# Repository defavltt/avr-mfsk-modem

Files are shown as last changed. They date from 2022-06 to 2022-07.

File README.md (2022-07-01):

# AVR MFSK (Multiple Frequency Shift Keying) modem transceiver

Original project based on ATmega88/168

Goertzel FFT based tone decoding for noisy audio links

Made specifically for radio use

## Features

 - Serial configurable: base frequency, frequency spacing and rate (~14 bits per second)

 - Repeated transmission of last data sent for performance testing

 - Audio input clipping indication

 - Automatic PTT control output

 - Automatic valid data checking

 - 8-bit sinewave output for regular audio channels

 - Suitable for keyboard-to-keyboard terminal operation

## Operation

There are two modem modes: normal operation / configuration. They are toggled by pressing the button

Configuring the parameters and enabling repeated transmission is done by going into configuration mode and sending a number corresponding to a byte that each of the it's double bits is a parameter value.

| param name | bit position | 0 | 1 | 2 | 3 |
|---|---|-----|-----|---|---|
| rtrans | 0 | off | on  | - | - |
| base freq  | 2 | 375 | 750 | 1125 | 1500 |
| freq space | 4 | 50  | 100 | 150  | 200  |
| rate* | 6 | 15  | 25  | 35 | 45 |

*the smaller the value the higher the bit rate

Examples:
```
88 > (01 01 10 00) - rtrans off, bf 2, fs 1, r 1
89 > (01 01 10 01) - rtrans on,  bf 2, fs 1, r 1

152 > (10 01 10 00) - rtrans off, bf 2, fs 1, r 2
```

While in configuration mode the LED shows audio input clipping. To set proper input level, a tone from a modem should be played into the input and the level adjusted to where the LED stops flickering. A solid light means too much signal is being fed.

Transmitting data/message is done by sending it by serial in normal operation mode.
Receiving data/message is only done in normal operation mode and retrieved from serial.

LED stays constantly on while: catching a preamble, receiving data/message and transmitting data/message.

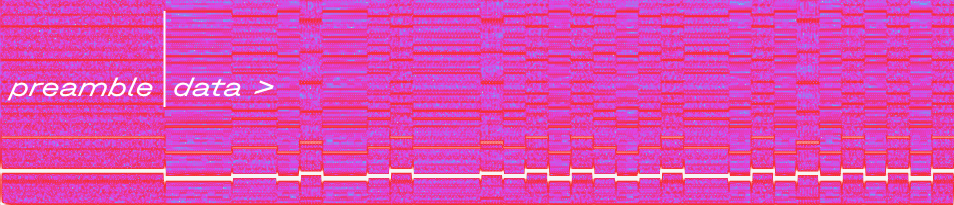
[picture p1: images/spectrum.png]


_spectral view of the transmission_

## Hardware

The PCB design is made for a 28-pin ATmega (QFN/MLF), whether that's 88, 168, 328, is a personal choice. Single-sided with some jumper wires required, vias are only for ground connection to the bottom layer.

Using an ATmega328 is encouraged, since originally an ATmega88 is used, flash usage is at ~99%, that limits adding more features.

There are pads left on the PCB for ISP programming and future use.

This project uses [MiniCore](https://github.com/MCUdude/MiniCore). Also a 16Mhz crystal is used.

Files for a 3D printed case are included. Case is held together by running a soldering iron along the seam of the top panel and main body.

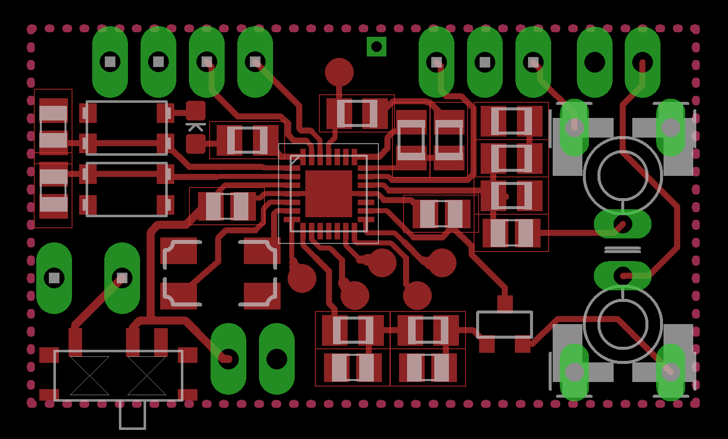
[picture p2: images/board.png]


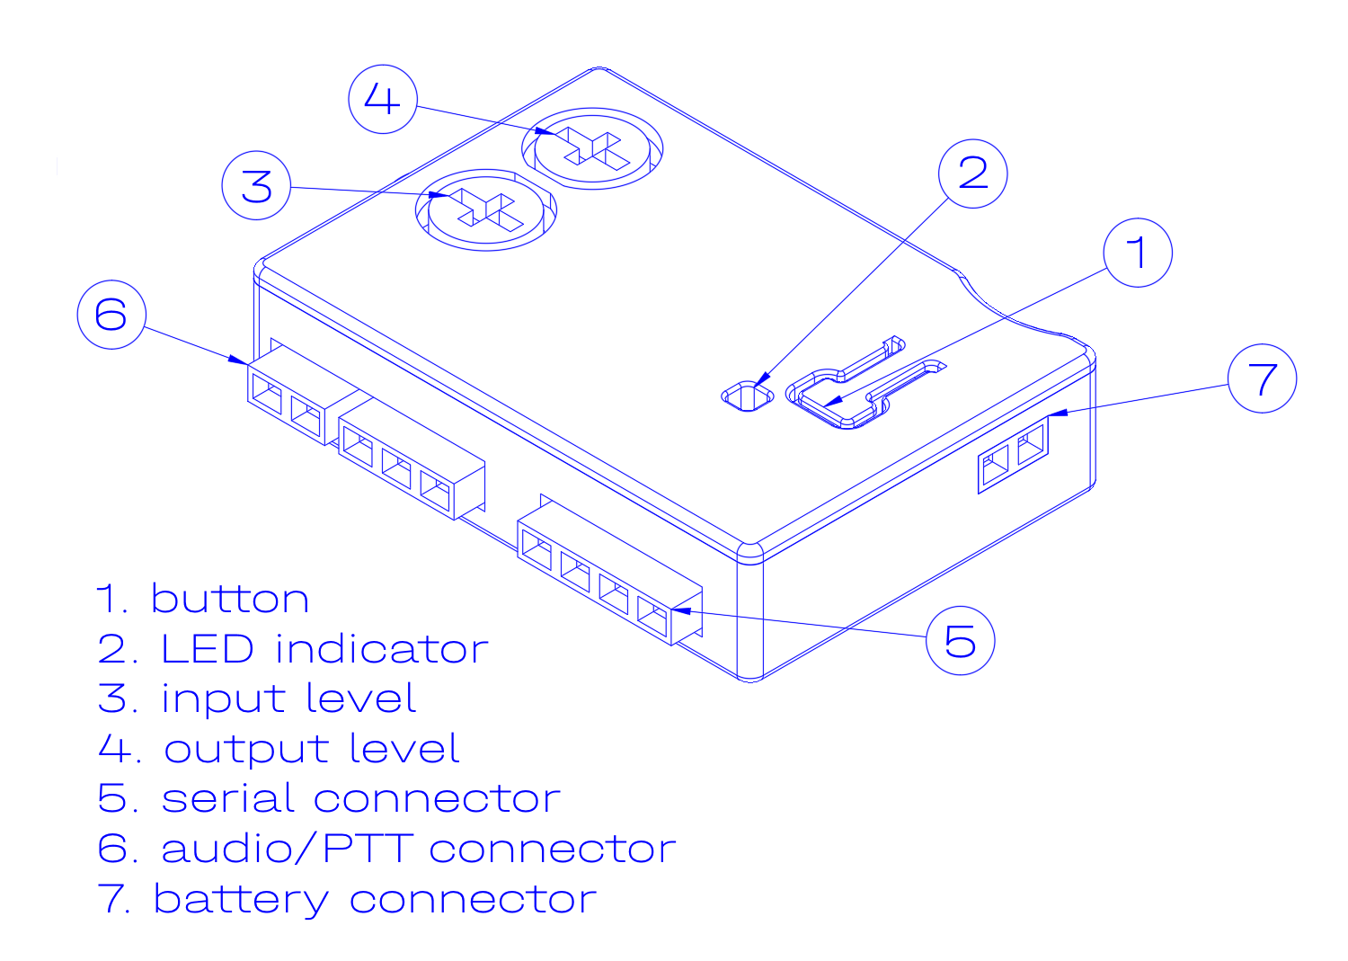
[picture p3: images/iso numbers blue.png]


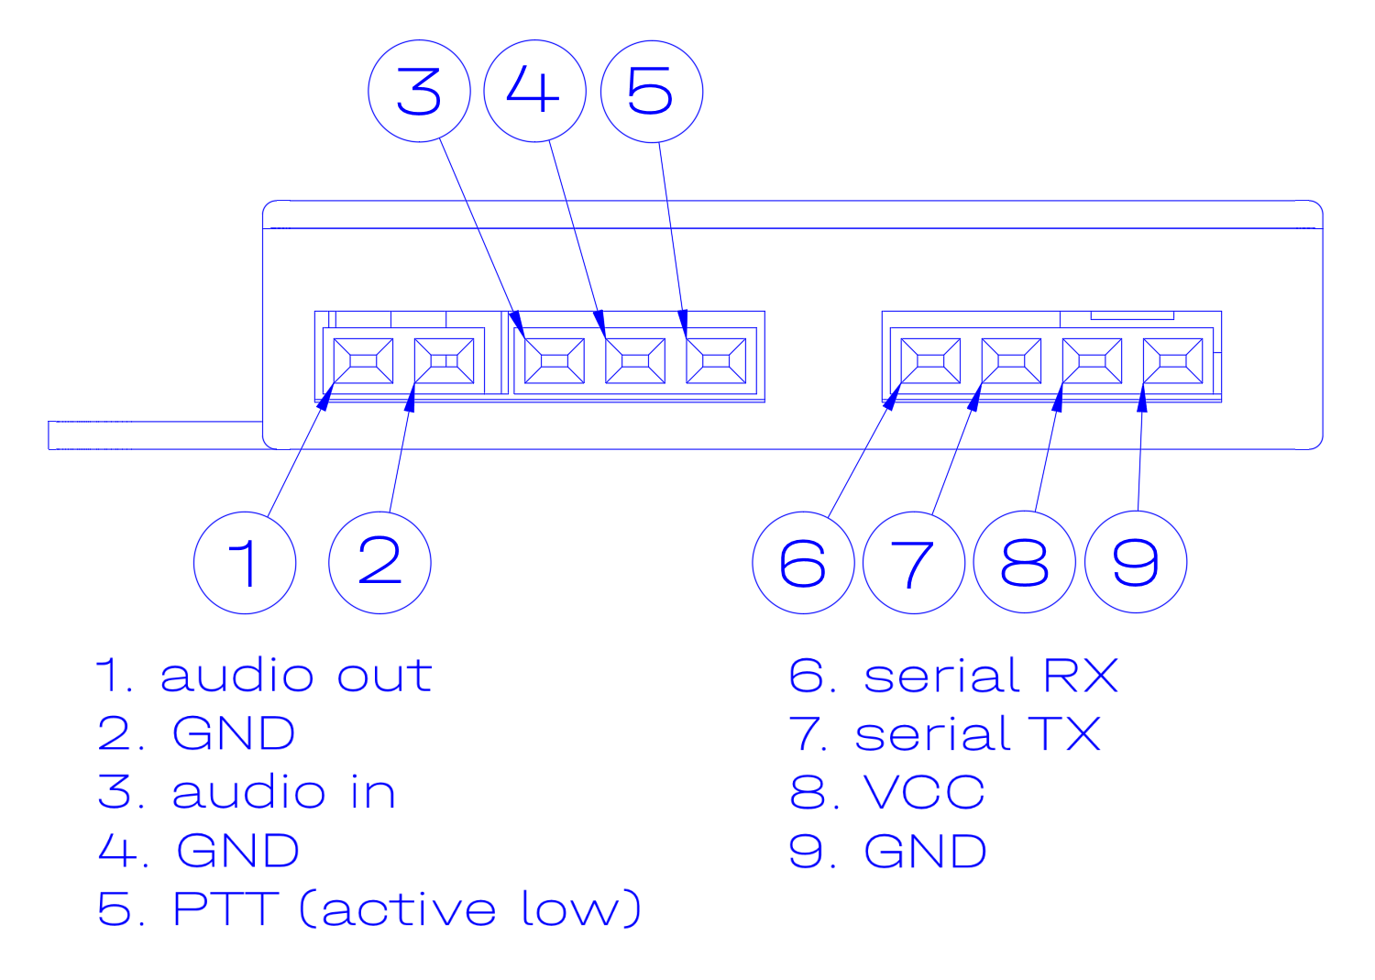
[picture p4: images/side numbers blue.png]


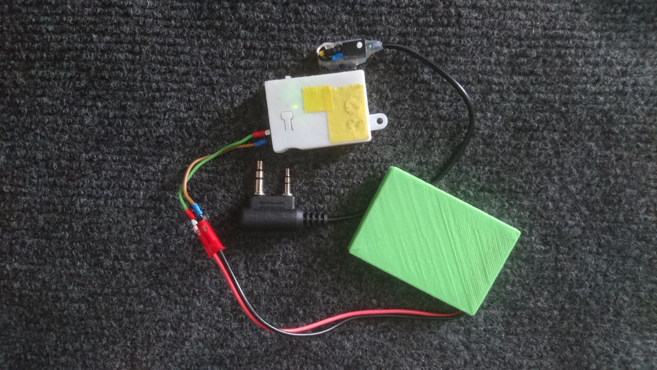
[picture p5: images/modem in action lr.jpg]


_modem powered on with a battery and connected with a kenwood style cable_

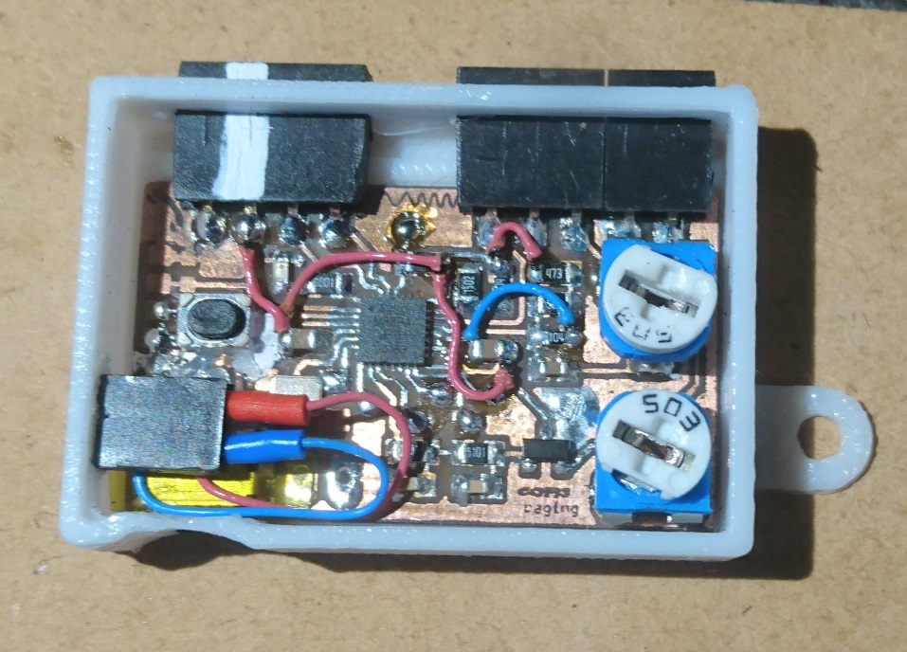
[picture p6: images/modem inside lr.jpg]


_bare modem_

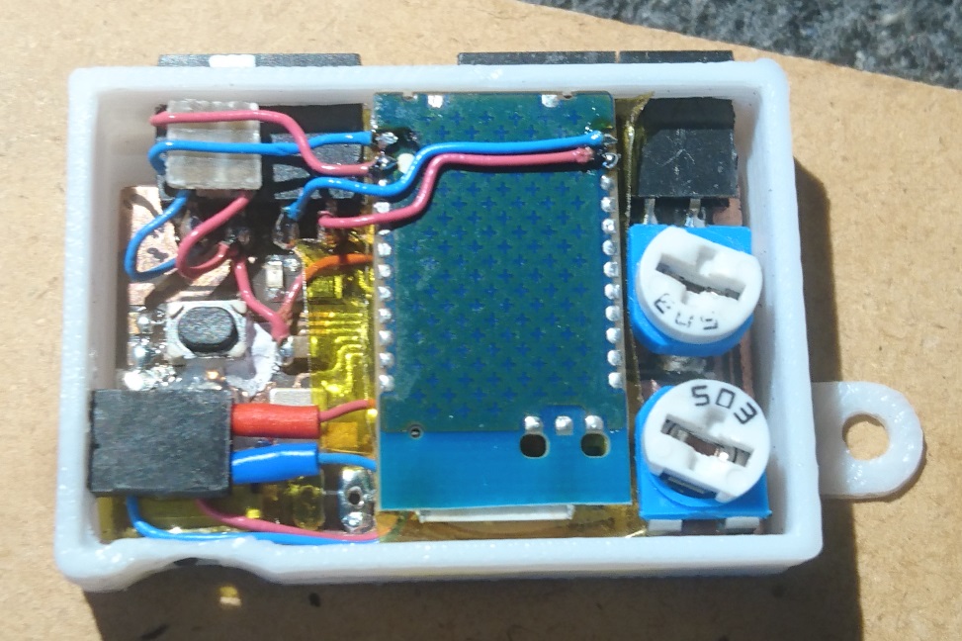
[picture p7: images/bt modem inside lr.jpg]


_modem with a bluetooth module added_

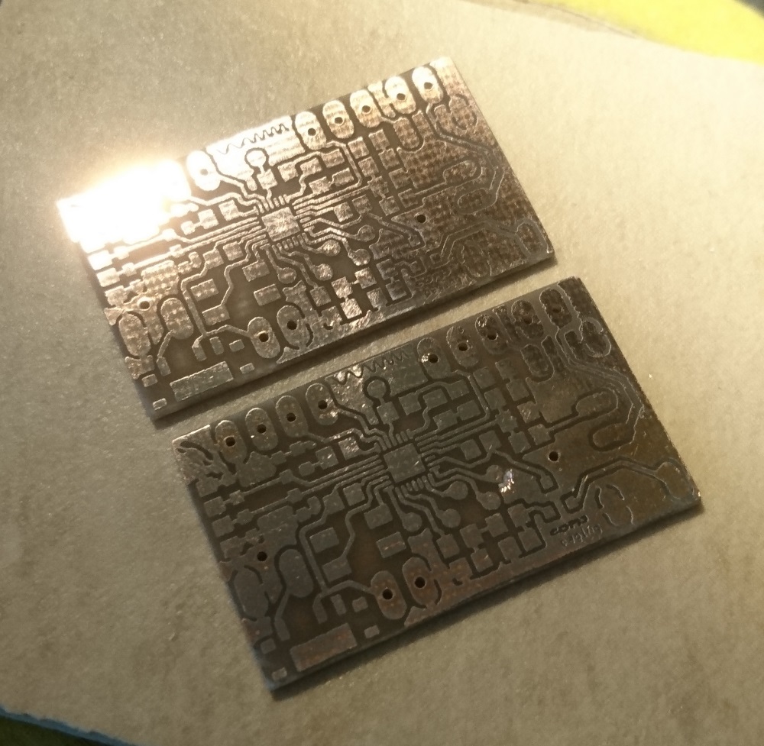
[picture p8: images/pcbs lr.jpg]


_toner method etched pcbs_

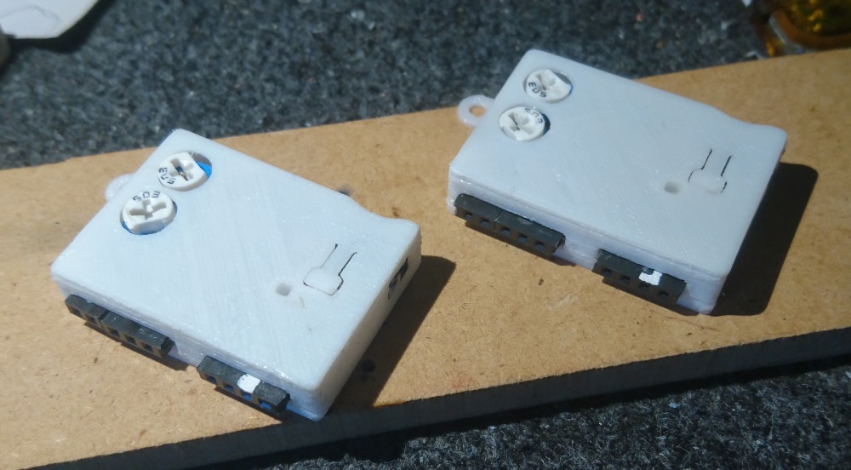
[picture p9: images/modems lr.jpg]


## Programming

 - Download and install [MiniCore](https://github.com/MCUdude/MiniCore)
 
 - Open code in IDE of choice
 
 - Configure board settings
 
   - Select your MCU and external 16Mhz clock
   
   - Leave the rest of the board settings by default
   
   - If want, you can enable bootloader and leave out a reset pin on the serial connector for future configuring of the key macros.
   
 - Flash via ISP programmer and it's done.

## Things to improve

 - Sometimes data doesn't sync
 - Sample tones more than one time and average them for better results in noisy audio
 - Make a better pwm filtering circuit

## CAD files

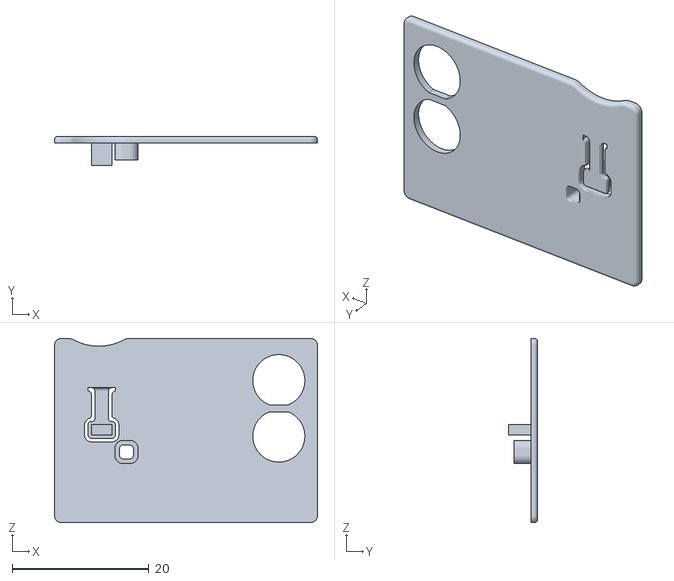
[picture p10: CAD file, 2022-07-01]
hardware/case/Modem Panel.stl
38.4 x 4.30 x 26.9

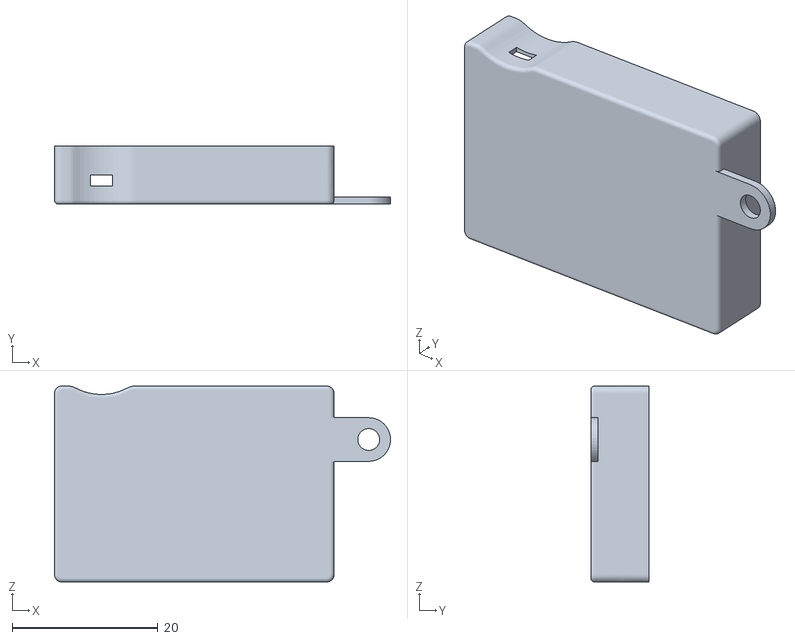
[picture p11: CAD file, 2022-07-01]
hardware/case/Modem Body.stl
46.1 x 8.00 x 26.9

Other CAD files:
hardware/case/modem transceiver only.f3d

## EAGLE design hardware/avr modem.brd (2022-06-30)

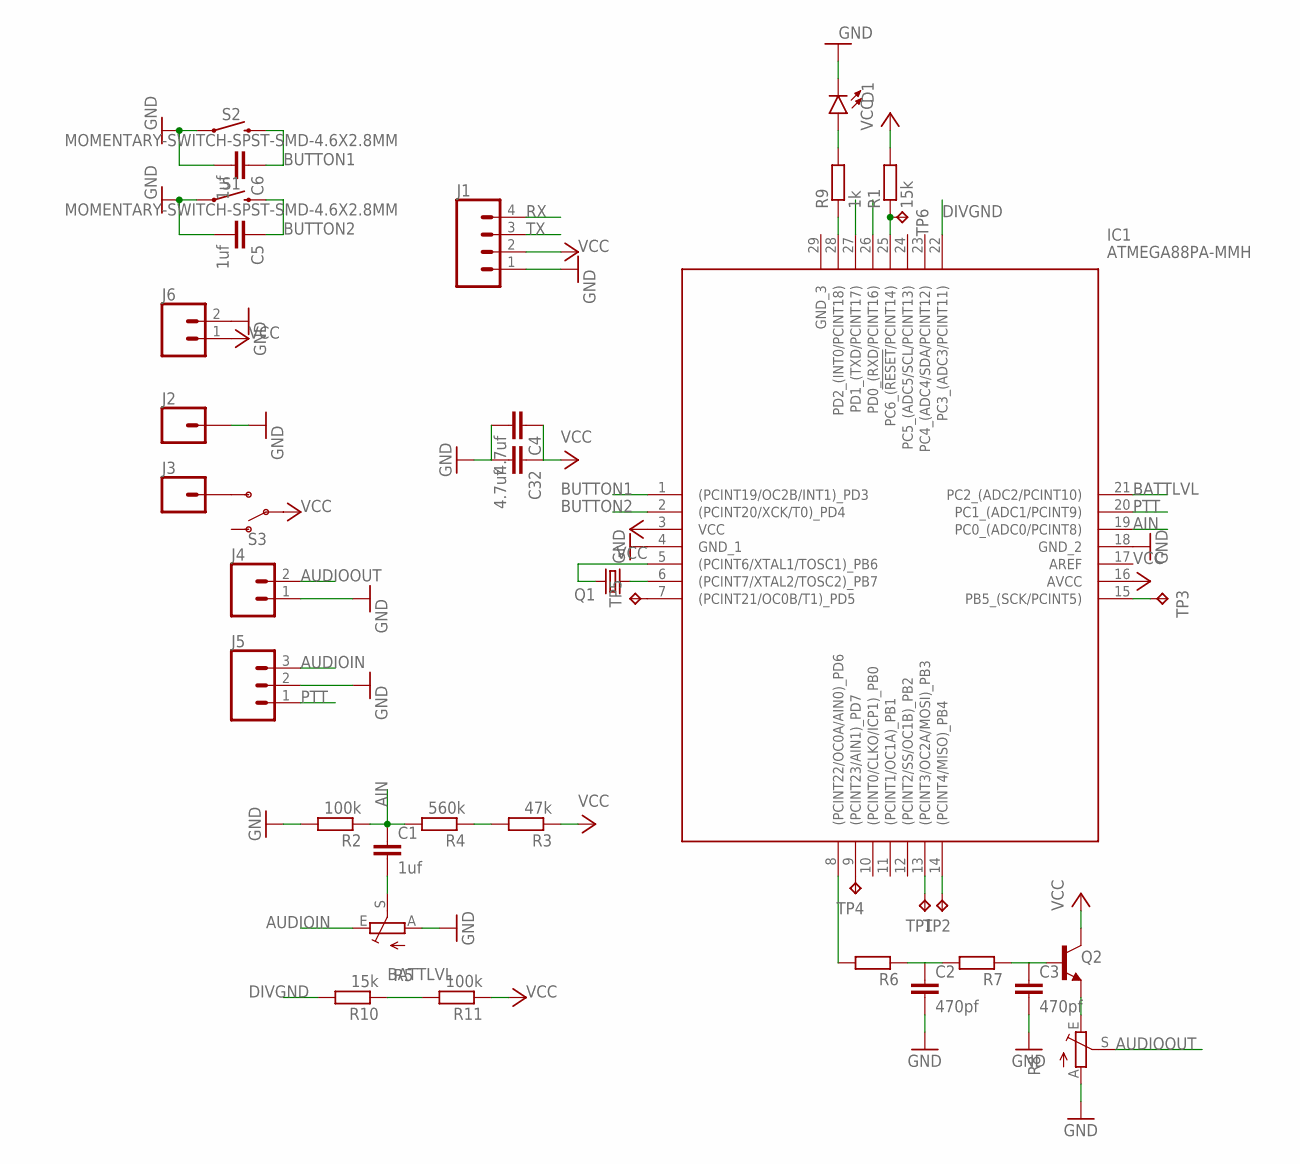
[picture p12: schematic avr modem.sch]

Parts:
C1, C5, C6: 1uf; C0805
C2, C3: 470pf; C0805
C4, C32: 4.7uf; C0805
D1: LED0603; LED-0603
IC1: ATMEGA88PA-MMH; QFN45P400X400X100-29N
J1: CONN_04LONGPADS; 1X04_LONGPADS
J2, J3: CONN_01PTH_LONGPAD; 1X01_LONGPAD
J4, J6: CONN_02PTH3; 1X02_LONGPADS
J5: CONN_03LONGPADS; 1X03_LONGPADS
Q1: CRYSTALCTS406; CTS406
Q2: TRANS_NPN-MMBTA42; SOT23-3
R1, R10: 15k; M0805
R2, R11: 100k; M0805
R3: 47k; M0805
R4: 560k; M0805
R5, R8: TRIM_EU-CA6V; CA6V
R6, R7: R-EU_M0805; M0805
R9: 1k; M0805
S1, S2: MOMENTARY-SWITCH-SPST-SMD-4.6X2.8MM; TACTILE_SWITCH_SMD_4.6X2.8MM
S3: SWITCH-SPDT-SMD-RIGHT-ANGLE; SWITCH_SPST_SMD_A
TP1, TP2, TP3, TP4, TP5, TP6: TPTP15R; TP15R

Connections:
AIN: C1.1, IC1.19 (PC0_(ADC0/PCINT8)), R2.1, R4.2
AUDIOIN: J5.3, R5.E
AUDIOOUT: J4.2, R8.S
BATTLVL: IC1.21 (PC2_(ADC2/PCINT10)), R10.1, R11.2
BUTTON1: C6.1, IC1.1 ((PCINT19/OC2B/INT1)_PD3), S2.3 (2), S2.4 (2)
BUTTON2: C5.1, IC1.2 ((PCINT20/XCK/T0)_PD4), S1.3 (2), S1.4 (2)
DIVGND: IC1.22 (PC3_(ADC3/PCINT11)), R10.2
GND: C2.2, C3.2, C4.2, C5.2, C6.2, C32.2, D1.C, IC1.4 (GND_1), IC1.18 (GND_2), J1.1, J2.1, J4.1, J5.2, J6.2, R2.2, R5.A, R8.A, S1.1, S1.2 (1), S2.1, S2.2 (1)
unnamed: IC1.6 ((PCINT7/XTAL2/TOSC2)_PB7), Q1.1
unnamed: IC1.5 ((PCINT6/XTAL1/TOSC1)_PB6), Q1.3 (2)
unnamed: IC1.25 (PC6_(!RESET!/PCINT14)), R1.1, TP6.TP
unnamed: IC1.14 ((PCINT4/MISO)_PB4), TP2.TP
unnamed: IC1.15 (PB5_(SCK/PCINT5)), TP3.TP
unnamed: IC1.13 ((PCINT3/OC2A/MOSI)_PB3), TP1.TP
unnamed: R3.2, R4.1
unnamed: C1.2, R5.S
unnamed: IC1.8 ((PCINT22/OC0A/AIN0)_PD6), R6.2
unnamed: C2.1, R6.1, R7.2
unnamed: C3.1, Q2.1 (B), R7.1
unnamed: IC1.28 (PD2_(INT0/PCINT18)), R9.1
unnamed: D1.A, R9.2
unnamed: J3.1, S3.3 (S)
unnamed: IC1.9 ((PCINT23/AIN1)_PD7), TP4.TP
unnamed: IC1.7 ((PCINT21/OC0B/T1)_PD5), TP5.TP
unnamed: Q2.2 (E), R8.E
PTT: IC1.20 (PC1_(ADC1/PCINT9)), J5.1
RX: IC1.26 (PD0_(RXD/PCINT16)), J1.4
TX: IC1.27 (PD1_(TXD/PCINT17)), J1.3
VCC: C4.1, C32.1, IC1.3 (VCC), IC1.16 (AVCC), J1.2, J6.1, Q2.3 (C), R1.2, R3.1, R11.1, S3.2

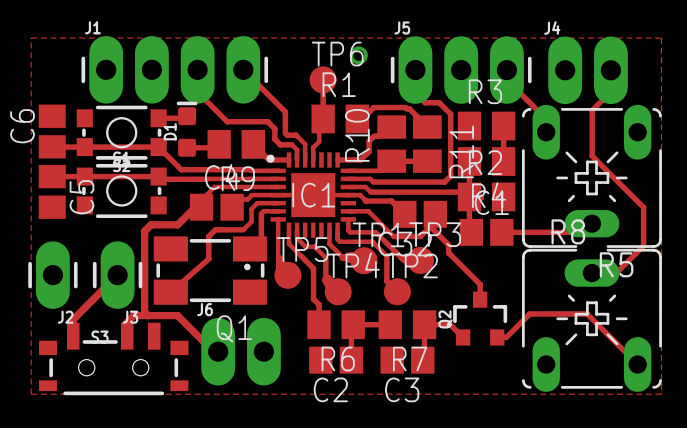
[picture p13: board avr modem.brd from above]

Board: 2 copper layers, 37 parts (0 on the bottom side), 29 nets.

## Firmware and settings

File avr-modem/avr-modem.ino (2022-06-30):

#define delayfix 64 //timer 0 compensation

#define N 256
#define IX_LEN 4

uint8_t samples[N];
volatile uint16_t samplePos = 0;

float spectrum[IX_LEN];

float cos_t[IX_LEN];
float sin_t[IX_LEN];

const uint16_t window = 256; //buffer size
const float samplerate = 9615.0;

const float pi = 3.14159265359;

byte sine64[] = {140,153,165,177,188,199,209,218,226,234,240,246,250,253,255,255,255,253,250,246,240,234,226,218,209,199,188,176,165,152,140,128,115,103,90,79,67,56,46,37,29,21,15,9,5,2,0,0,0,2,5,9,15,21,29,37,46,56,67,78,90,102,115,128};
byte wave1out;
float wave1ptr;

//float modemtones[IX_LEN] = {1000, 1100, 1200, 1300};
float modemtones[IX_LEN];

float frequency = 1000.0f;
uint8_t modemspeed;
int modemtonespace = 100;
int modembasefreq = 1000;
uint8_t setmodemspeed = 15; //15,25,35,45
uint16_t modempreamble = 500; //0-1000
float modemthreshold = 3000; //set above noise level


uint16_t doublebitpointer;
bool modemtransmitting;
uint8_t modemsymbol; //being a local var instead of a global causes problems

volatile uint16_t tickcount;
volatile bool tick;

uint8_t statusled; //0 - off, 1 - on, 2 - blink
bool blinkled;
uint8_t blinktimer;

bool lastbuttonstate;
bool modetoggle; //0 - receiving, 1 - config
bool rtrans = 0;

uint16_t rtranstimer;

uint8_t header[2] = {'@', '!'}; //ballast of 2 bytes required after that a special character
uint8_t datamsg[34];
uint8_t datarecv[34];
uint8_t rxstatereturn;

void setup() {
  cli();
  initADC();
  sei();

  pinMode(2, OUTPUT); //led
  digitalWrite(2, HIGH);
  
  pinMode(6, OUTPUT); //pwm out

  pinMode(15, INPUT); //ptt, low to transmit

  pinMode(5, OUTPUT); //debug

  pinMode(4, INPUT_PULLUP); //button 2

  if(!digitalRead(4)) { //choose serial speed a startup
    while(!digitalRead(4)) { } //wait to let go of button
    Serial.begin(9600);
  } else {
    Serial.begin(115200);
  }

  analogReference(INTERNAL);

  //timer0
  TCCR0A = 0b10100011; //fast pwm mode
  TCCR0B = 0b00000001;

  //timer2
  TCCR2A = 0b00000010; //ctc mode
  TCCR2B = 0b00000111;
  OCR2A = 127;

  TIMSK2 = 0b00000010; //enable timer interrupts for sampling

  settones(modemtonespace, modembasefreq);
}

void loop() {
  bool buttonstate = digitalRead(4);
  if(buttonstate == LOW && buttonstate != lastbuttonstate) {
    modetoggle = !modetoggle;
    flashled(); //flash led to confirm press
  }
  lastbuttonstate = buttonstate;
  
  if(0 < Serial.available()) {
    if(modetoggle) { //config
      uint16_t value = Serial.parseInt();
      rtrans = doublebitread(value, 0); //rtrans
      modembasefreq = 375 * (doublebitread(value, 1) + 1); //base freq
      modemtonespace = 50 * (doublebitread(value, 2) + 1); //freq spacing
      setmodemspeed = 10.0 * (doublebitread(value, 3) + 1.5); //modem speed
      settones(modemtonespace, modembasefreq);
      rtranstimer = 0;
    } else { //receiving
      String serialread = Serial.readString();
      strcpy((char*)datamsg, serialread.c_str()); //put message from serial to buffer
      addheader(datamsg, sizeof(datamsg));
      modemtx(datamsg, strlen((char*)datamsg)+1, setmodemspeed, modempreamble);
      statusled = 2; //blink
    }
  }
  if(modetoggle) {
    detectclipping();
  } else {

    
    switch(statusled) {
      case 0: //off
        digitalWrite(2, 0);
        break;
      case 1: //on
        digitalWrite(2, 1);
        break;
      case 2: //blink
        blinktimer++;
        if(blinktimer > 16) {
          blinkled = !blinkled; //toggle
          digitalWrite(2, blinkled);
          blinktimer = 0;
        }
        break;
    }

    if(rtrans) {
      rtranstimer++;
      if(rtranstimer > 1023) {
        rtranstimer = 0; //reset
        modemtx(datamsg, strlen((char*)datamsg)+1, setmodemspeed, modempreamble);
      }
    }
    
    modemrx(datarecv, sizeof(datarecv), setmodemspeed, modemthreshold);
    statusled = 2; //blink
    if(rxstatereturn > 0) {
      bool validmsg = detectcorrectarrayshift(datarecv, sizeof(datarecv), 8, 2, '!'); //find right array double bit aligment
      if(validmsg) {
        removefirstchar(datarecv, sizeof(datarecv));
        Serial.println((char*)datarecv);
//        delay(500 * delayfix);
//        delay(500 * delayfix);
//        delay(500 * delayfix);
//        delay(500 * delayfix);
      }
    }
//    switch(rxstatereturn) {
//      case 1: //signal end
//        Serial.println("signal end");
//        break;
//      case 2: //array ovf
//        Serial.println("array ovf");
//        break;
//    }
  }
}

ISR(ADC_vect) {
//  PORTD = 0b10000000; //sampling rate debug
//  PORTD = 0b00000000;
  if(modemtransmitting) {
    wave1ptr += 64.0f * frequency / samplerate;
    while(wave1ptr >= 64.0f) {
      wave1ptr -= 64.0f;
    }
    OCR0A = (sine64[(int)wave1ptr]);
  } else {
    uint16_t sample = ADC;

    samples[samplePos++] = sample;
    
    if(samplePos >= N) {
      ADCSRA &= ~_BV(ADIE); // Buffer full, interrupt off
    }
  }
}

ISR(TIMER2_COMPA_vect) {
  tickcount++;
  if(tickcount > modemspeed) {
    tickcount = 0; //reset
    tick = 1; //set tick
  }
}

void initADC() {
  ADMUX = 0b01000000;
  ADCSRA = 0b11101111;
  ADCSRB = 0; // Free-run mode
}

void goertzel(uint8_t *samples, float *spectrum) {
  float v_0, v_1, v_2;
  float re, im, amp;
    
  for (uint8_t k = 0; k < IX_LEN; k++) {
    float c = cos_t[k];
    float s = sin_t[k];
    
    float a = 2. * c;
    v_0 = v_1 = v_2 = 0;  
    for (uint16_t i = 0; i < N; i++) {
      v_0 = v_1;
      v_1 = v_2;
      v_2 = (float)(samples[i]) + a * v_1 - v_0;
    }
    re = c * v_2 - v_1;
    im = s * v_2;
    amp = sqrt(re * re + im * im);
    spectrum[k] = amp;        
  } 
}

float calcfftfreqvalue(float freq, float samplerate, uint16_t window) {
  float k = 0.5 + ((window * freq) / samplerate);
  return (2 * (pi / window)) * k;
}

uint8_t spectrum2binary(float threshold) {
//    while(ADCSRA & _BV(ADIE)); // Wait for audio sampling to finish
  goertzel(samples, spectrum); //calculate fft each time the function is called
  debugpulse();
    samplePos = 0;
    ADCSRA |= _BV(ADIE); // Resume sampling interrupt
  for(byte i = 0; i < IX_LEN; i++) {
    if(spectrum[i] > threshold) {
      return i; //return active tone number (0-3) 4 - no tone
    }
  }
}

void doublebitbytewritemanual(uint8_t *input, uint8_t pointer, uint8_t value, uint8_t select) {
  input[pointer] |= value << select*2;
}

void doublebitbytewrite(uint8_t *input, uint8_t value) {
  uint16_t arrayptr = doublebitpointer / 4;
  input[arrayptr] |= value << (doublebitpointer % 4)*2;
  doublebitpointer++;
}

uint8_t doublebitread(uint8_t value, uint8_t select) {
  return (value >> select*2) & B00000011;
}

void modemtx(uint8_t *data, size_t len, uint16_t speed, uint16_t preamble) {
  const uint8_t freqoffset = 17; //compensate for fft offset
  uint8_t i = 0;
  uint8_t k = 0;
  modemspeed = speed;
  modemtransmitting = 1;
  digitalWrite(2, 1); //led on
  pinMode(15, OUTPUT);
  digitalWrite(15, LOW); //ptt on
  frequency = modemtones[3] + freqoffset; //preamble
  asm("NOP"); //bodge
  delay(preamble * delayfix);
  debugpulse();
  tickcount = 0; //start immediately
  while(true) { //payload
    if(tick) { //timing based on adc sample rate
      frequency = modemtones[doublebitread(datamsg[k], i)]  + freqoffset;
      debugpulse();
      i++;
      if(i >= 4) { //for each double bit (symbol)
        i = 0;
        k++;
        if(k >= len) { //for each byte from array
          pinMode(15, INPUT); //ptt off
          modemtransmitting = 0; //stop signal
          tick = 0;
          return; //exit while loop
        }
      }
      tick = 0; //clear tick
    }
  }
}

void modemrx(uint8_t *data, size_t len, uint16_t speed, float threshold) {
  modemspeed = speed;
  doublebitpointer = 0; //reset
  uint16_t symbolcount = 0;
  modemtransmitting = 0;
  if(spectrum2binary(threshold) == 4) { 
    rxstatereturn = 0;
    return;
  }
  if(spectrum2binary(threshold) == 3) { //detect preamble
//    debugpulse();
    digitalWrite(2, 1); //led on
    erasedata(data, len); //erase message buffer if a preamble is detected
    while(spectrum2binary(threshold) == 3) { //wait for preamble to end
      //pause
    }
  }
  delay(132 * delayfix); //132 - speed 15 / 265 - speed 30
  tickcount = 0; //start immediately
  while(true) { //start assembling data
    if(tick) { //timing based on adc sample rate
      modemsymbol = spectrum2binary(threshold); //detect tones
//      Serial.println(modemsymbol);
      if(modemsymbol == 4) { //no tone, stop receiving
        rxstatereturn = 1;
        return;
      }
//      debugpulse();
      doublebitbytewrite(data, modemsymbol); //put symbols into bytes, into an array
      symbolcount++;
      if(symbolcount / 4 > len) { //stop receiving to prevent overflow
        tick = 0; //clear tick
        rxstatereturn = 2;
        return;
      }
      tick = 0; //clear tick
    }
  }
}

void debugpulse() {
  digitalWrite(7, HIGH);
  delay(1);
  digitalWrite(7, LOW);
}

void detectclipping() {
  digitalWrite(2, LOW);
  for(byte i = 0; i < 8; i++) {
    if(samples[i] <= 10 || samples[i] >= 240) {
      digitalWrite(2, HIGH);
    }
    samplePos = 0;
    ADCSRA |= _BV(ADIE); // Resume sampling interrupt
  }
}

void doublebitshift(uint8_t *input, size_t len, bool direction) { //0 - left, 1 - right
  uint8_t bitbuf = 0;
  if(direction) { //right
    for(byte i = len; i > 0; i--) {
      input[i-1] >>= 2;
      bitbuf = doublebitread(input[i-2], 0);
      doublebitbytewritemanual(input, i-1, bitbuf, 3);
    }
  } else { //left
    for(byte i = 0; i < len; i++) {
      input[i] <<= 2;
      bitbuf = doublebitread(input[i+1], 3);
      doublebitbytewritemanual(input, i, bitbuf, 0);
    }
  }
}

bool detectcorrectarrayshift(uint8_t *input, size_t len, uint8_t level, uint8_t depth, uint8_t character) {
  for(byte i = 0; i < level; i++) { //sift to the left
    doublebitshift(input, len, 0);
//    Serial.print('<'); Serial.println(i);
    for(byte k = 0; k < depth; k++) { //search from the array beginning at a desired length
      if(input[k] == character) {
        return 1; //return valid
      }
    }
  }
  return 0; //invalid message
}

void calcfftvalues(float *input) {
  for(byte i = 0; i < IX_LEN; i++) { //calculate values for fft to work with
    float w = calcfftfreqvalue(modemtones[i], samplerate, window);
    cos_t[i] = cos(w);
    sin_t[i] = sin(w);
  }
}

void settones(int space, int freq) {
  for(byte i = 0; i < IX_LEN; i++) {
    modemtones[i] = freq + (space * i);
  }
  calcfftvalues(modemtones);
}

void erasedata(uint8_t *data, size_t len) {
  for(byte i = 0; i < len; i++) {
    data[i] = 0;
  }
}

void flashled() {
  for(byte i = 0; i < 4; i++) {
    digitalWrite(2, 1);
    delay(100 * delayfix);
    digitalWrite(2, 0);
    delay(100 * delayfix);
  }
}

void removefirstchar(uint8_t *data, size_t len) {
  uint8_t buf = 0;
  for(byte i = 0; i < len; i++) {
    buf = data[i+1];
    data[i] = buf;
  }
}

void movecharstoright(uint8_t *data, size_t len) {
  uint8_t buf = 0;
  for(byte i = len-1; i > 0; i--) { //might be len-1
    buf = data[i-1];
    data[i] = buf;
  }
}

void addheader(uint8_t *data, size_t len) {
  movecharstoright(data, len); //make 2 byte free space in the beginning for the header
  movecharstoright(data, len);
  data[0] = header[0];
  data[1] = header[1];
}

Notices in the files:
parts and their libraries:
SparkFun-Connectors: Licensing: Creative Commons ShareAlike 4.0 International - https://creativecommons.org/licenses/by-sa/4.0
